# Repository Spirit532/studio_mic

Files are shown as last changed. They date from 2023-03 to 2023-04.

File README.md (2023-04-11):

# Simple, high quality condenser microphone for under $100

I needed a good quality microphone, but all of the options available were either a bit pricy or just not really good in performance, so I decided to build my own.

The microphone build uses a clone RK12/CK12 capsule($40-50 on Aliexpress/Ebay/etc, search for "edge terminated capsule"), a U87 donor body($15-30, also Aliexpress, search term "U87 mic"), and a custom preamp board($20-30, this project).

The board is very simple, yet high performance - it uses a dual FET input opamp in a single package to both convert the capsule's impedance and provide a differential signal, while the bias is provided by a slightly cursed hex schmitt trigger inverter charge pump.

With the setup pictured below, the results are, to the non-audiophool ear, perfect. There is practically no self-noise due to the simplicity of the circuit and performance of the chosen opamp, plenty of dynamic range, and no signal distortion/"coloration". You get exactly what the capsule sees on the XLR connector.

#### Notes about component choice
  1. You can use pretty much any FET input opamp, **however** you must pay close attention to the quiescent current. This circuit uses a fairly high impedance power path, and the phantom power standard can't provide much current in the first place. Total power consumption of the two opamps should be no more than ~7-8mA(3.5-4mA per).

  2. Same goes for the hex inverter in terms of power consumption, but otherwise anything will do. You can substitute the part with any 40106 clone of similar functionality.
  
  3. Take care to purchase high voltage rated capacitors where specified - this is important! Ceramic capacitors lose capacitance at higher voltages, so X7R class caps rated at 100V or more are preferred(this won't explicitly solve derating, but it will help). All values are  readily available in 0805 size, so it's not an issue.

  4. Choose NP0/C0G capacitors for ceramics if your budget allows. They'll improve performance a little bit, but not by a whole lot. (this will solve derating, but at significant cost)
  
The design is licensed under the MIT license. If you want to build it, go ahead. If you want to sell it, also go ahead, but just mention this page or something. Pretty much none of this is really original and has been done dozens of times(i.e. DJJules/Sound Sleuth over at Instructables, whose circuit I took inspiration from), I just put my own twist on it.

#### Important note about cheap donor bodies
Most cheap donor bodies will come pre-anodized or even pre-painted, including contact surfaces at separation points(circuit cover, headbasket, nut, spacers, etc), __make sure to sand them down__ to expose metal, or you'll pick up tons of mains hum and other external electrical noise!

## Get the board
If you can't make or assemble the board yourself, you can order them here(shared PCBWay project, if you order there I get commission at no cost to you)

https://www.pcbway.com/project/shareproject/Simple_ultra_high_performance_condenser_microphone_circuit_495ce39d.html

## Schematic
(also available as pdf or KiCad 7 sources, see files)

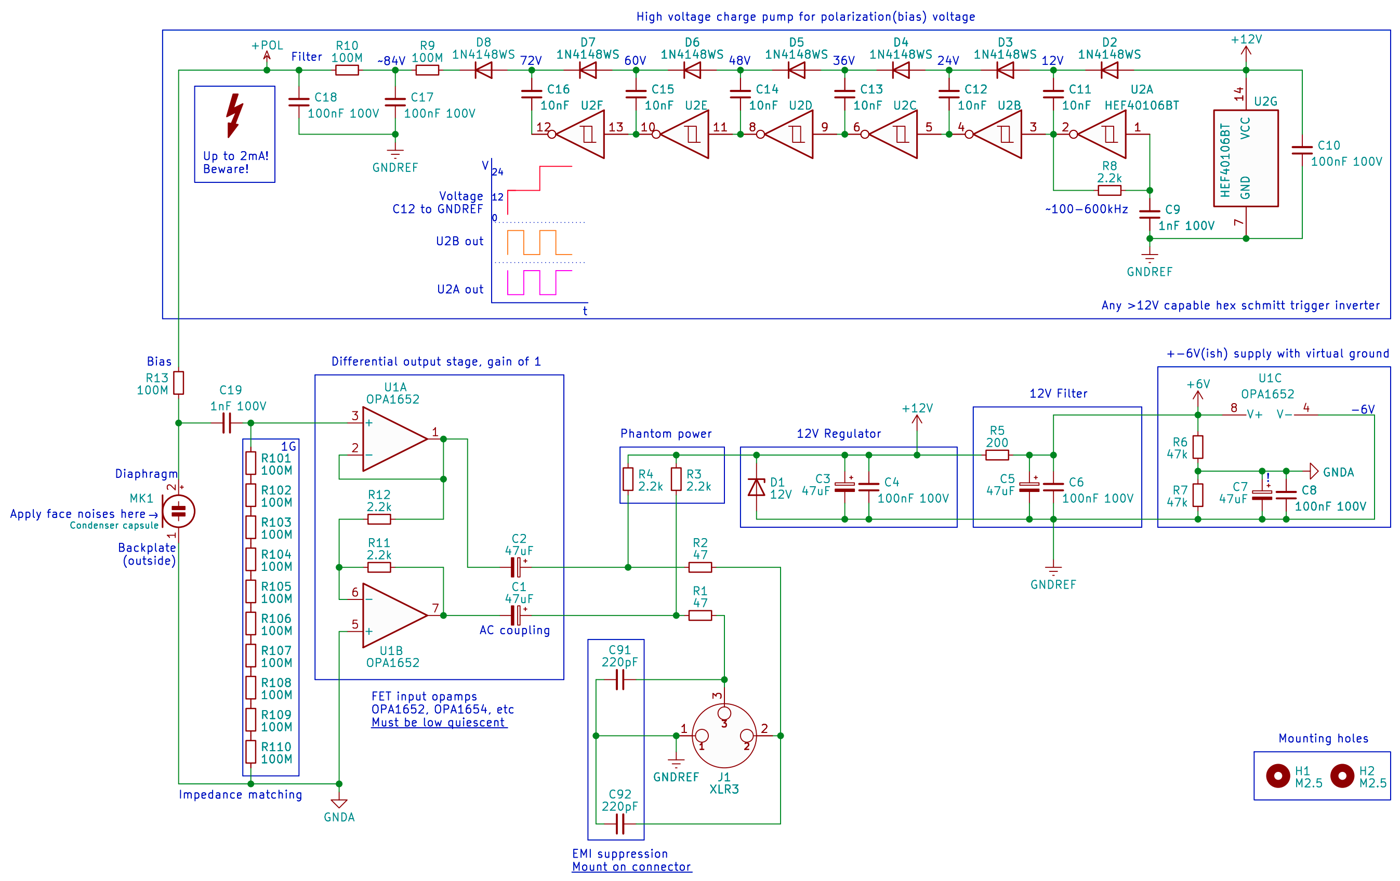
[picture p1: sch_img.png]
Schematic


## PCB render
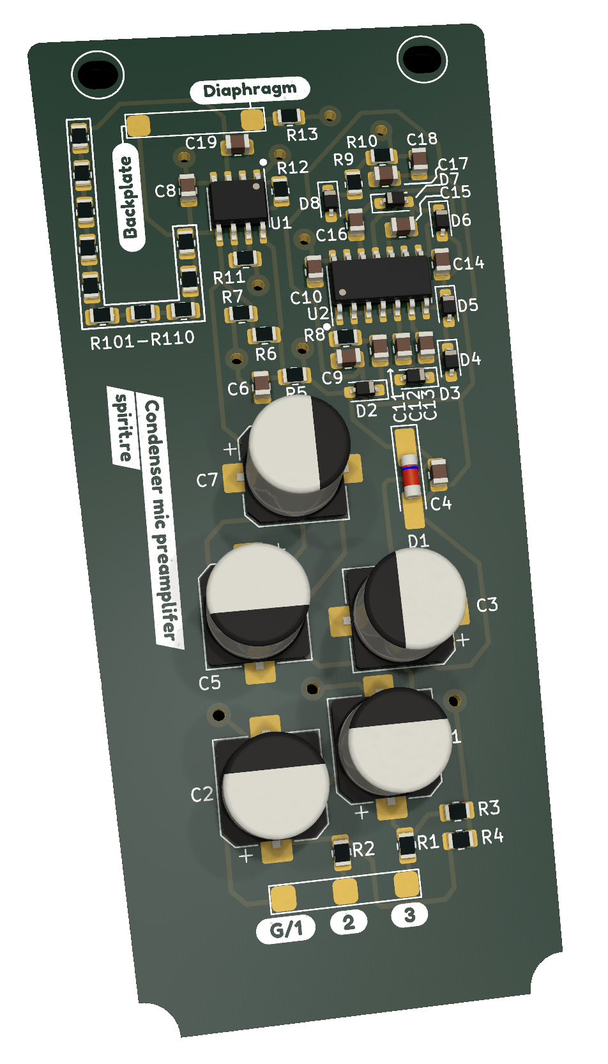
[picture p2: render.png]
Render


## Assembled board, DIY single-layer version(homemade)
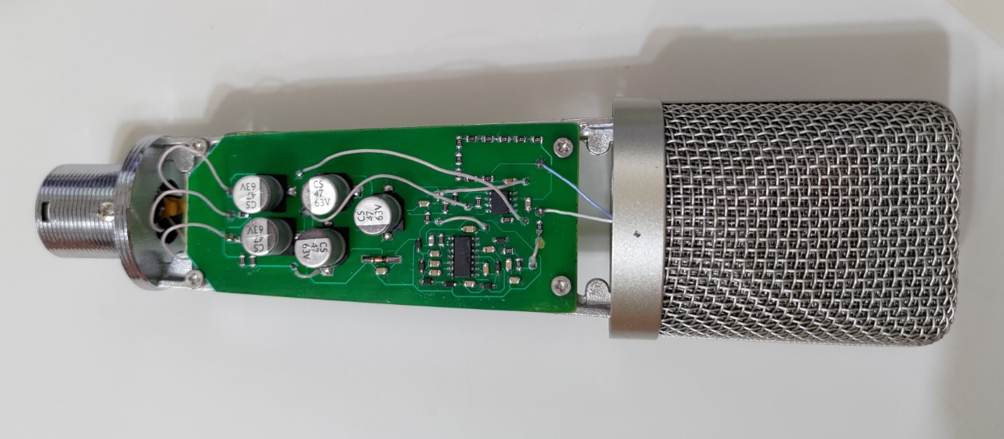
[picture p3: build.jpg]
Build


## Capsule mounted in the donor body
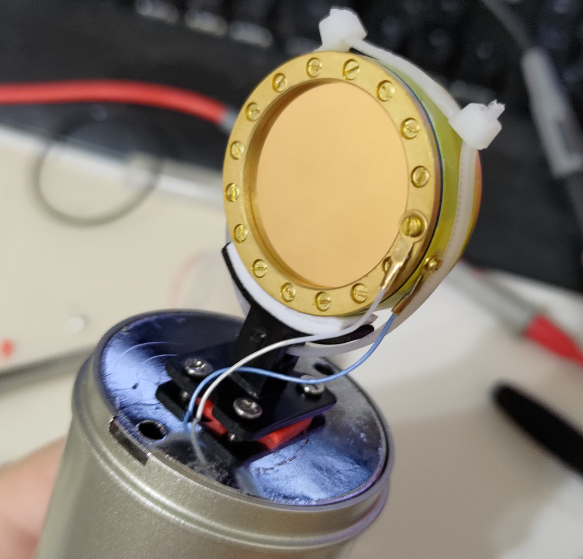
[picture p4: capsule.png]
Capsule


## U87 clone donor body
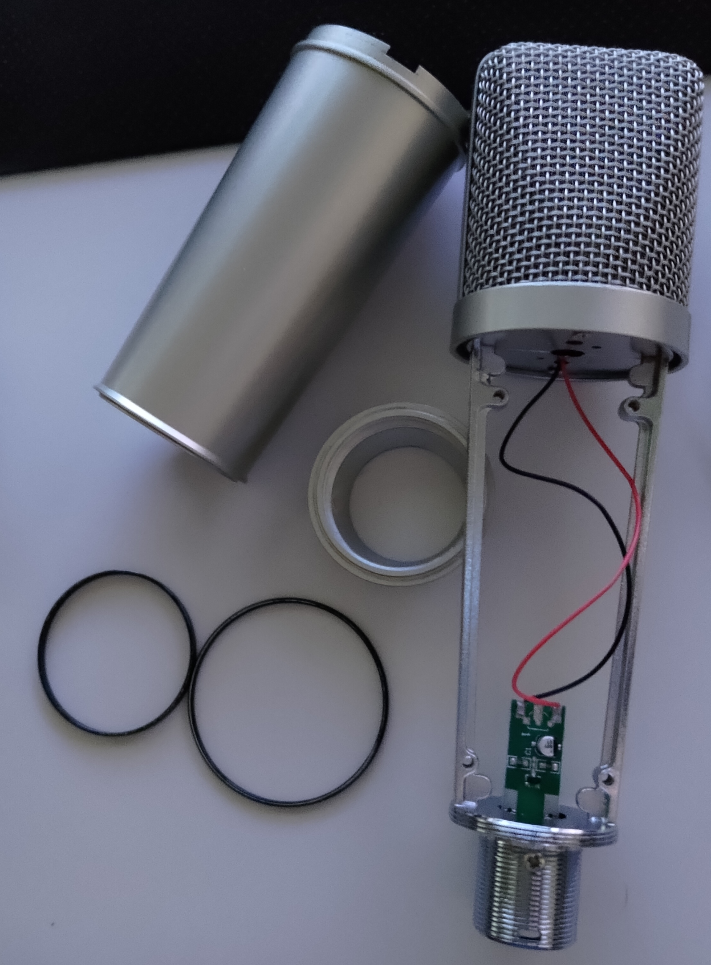
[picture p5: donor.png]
Donor


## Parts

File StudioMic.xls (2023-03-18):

Reference | Value | Footprint | Qty
C1-C3, C5, C7 | 47uF 63V | Capacitor_SMD:CP_Elec_8x10.5 | 5
C4, C6, C8, C10, C17, C18 | 100nF 100V | Capacitor_SMD:C_0805_2012Metric | 6
C9, C19 | 1nF 100V | Capacitor_SMD:C_0805_2012Metric | 2
C11-C16 | 10nF | Capacitor_SMD:C_0805_2012Metric | 6
C91, C92 | 220pF | Mount on connector, not on PCB | 2
D1 | 12V | Diode_SMD:D_MiniMELF_Handsoldering | 1
D2-D8 | 1N4148WS | Diode_SMD:D_SOD-323_HandSoldering | 7
H1, H2 | Screw, M2.5 | PCB mounting | 4
J1 | U87 housing, XLR connector | Comes with the housing | 0
MK1 | Condenser capsule | CK12, K67, K47, M7, pick one | 1
R1, R2 | 47 | Resistor_SMD:R_0805_2012Metric | 2
R3, R4, R8, R11, R12 | 2.2k | Resistor_SMD:R_0805_2012Metric | 5
R5 | 200 | Resistor_SMD:R_0805_2012Metric | 1
R6, R7 | 47k | Resistor_SMD:R_0805_2012Metric | 2
R9, R10, R13, R101-R110 | 100M | Resistor_SMD:R_0805_2012Metric | 13
U1 | OPA1652 | Package_SO:SOIC-8_3.9x4.9mm_P1.27mm | 1
U2 | HEF40106BT | Package_SO:SO-14_3.9x8.65mm_P1.27mm | 1

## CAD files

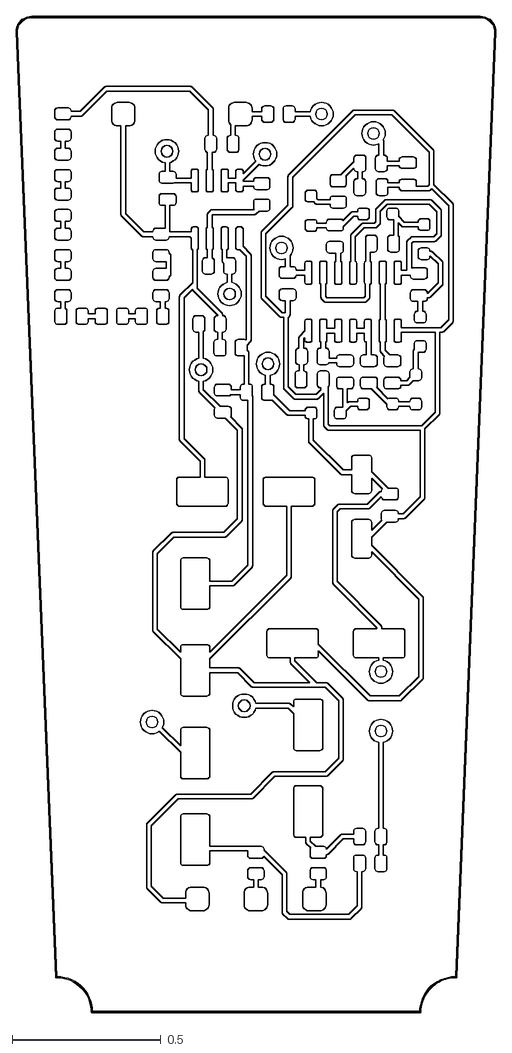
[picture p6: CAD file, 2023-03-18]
DXF/StudioMic-F_Cu.dxf
1.61 x 3.35

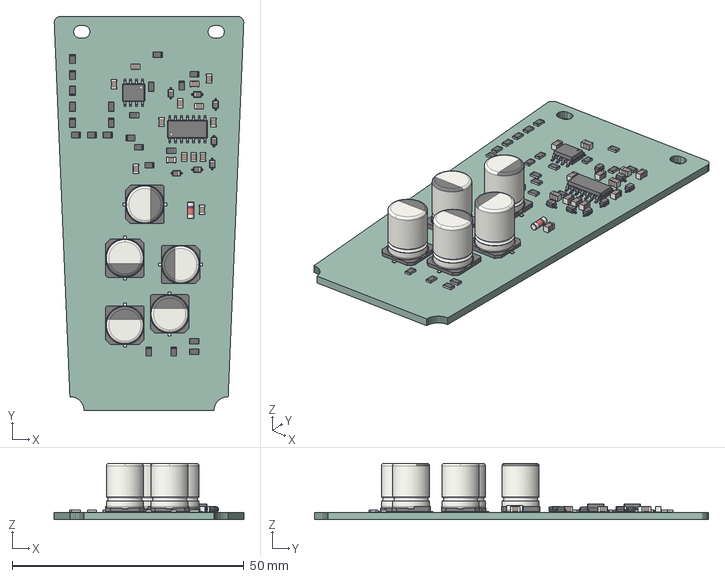
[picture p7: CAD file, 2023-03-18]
StudioMic.step
40.9 x 85.0 x 12.1 mm
PCB

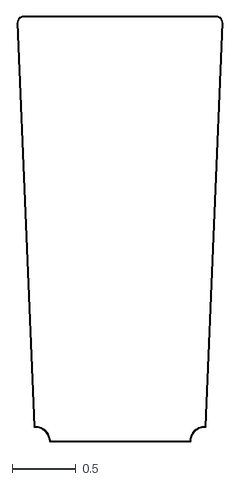
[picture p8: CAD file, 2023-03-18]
DXF/StudioMic-Edge_Cuts.dxf
1.61 x 3.35

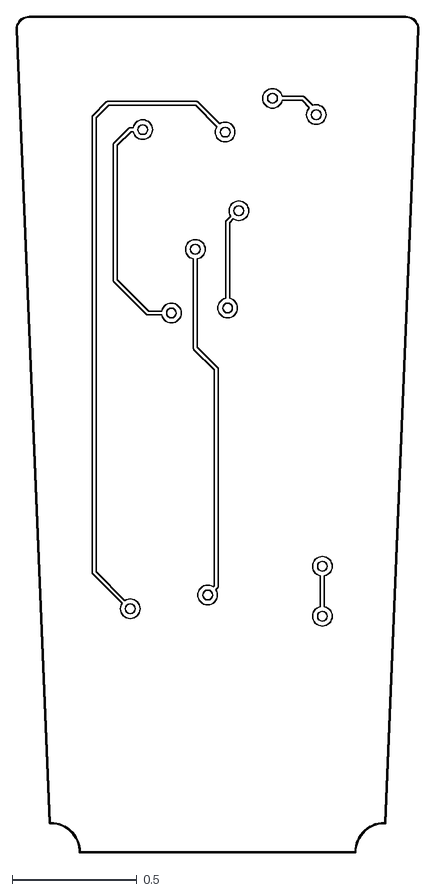
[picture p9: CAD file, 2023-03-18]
DXF/StudioMic-B_Cu.dxf
1.61 x 3.35

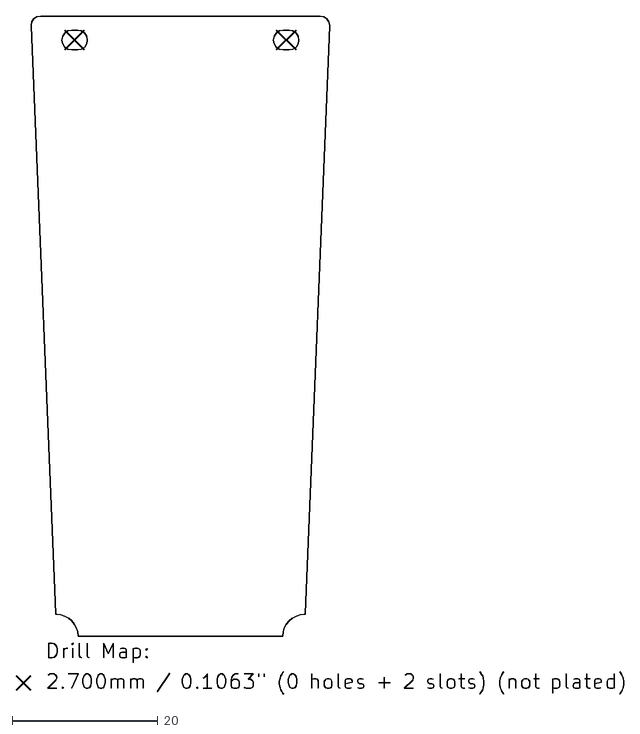
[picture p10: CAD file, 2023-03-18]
DXF/StudioMic-NPTH-drl_map.dxf
83.3 x 92.9

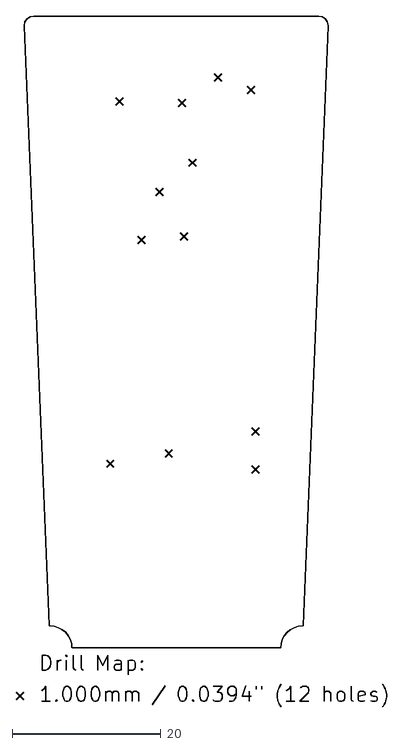
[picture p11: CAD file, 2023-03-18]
DXF/StudioMic-PTH-drl_map.dxf
49.8 x 92.9

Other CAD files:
DXF/StudioMic-B_Mask.dxf
DXF/StudioMic-F_Mask.dxf
DXF/StudioMic-F_Paste.dxf
DXF/StudioMic-F_Silkscreen.dxf

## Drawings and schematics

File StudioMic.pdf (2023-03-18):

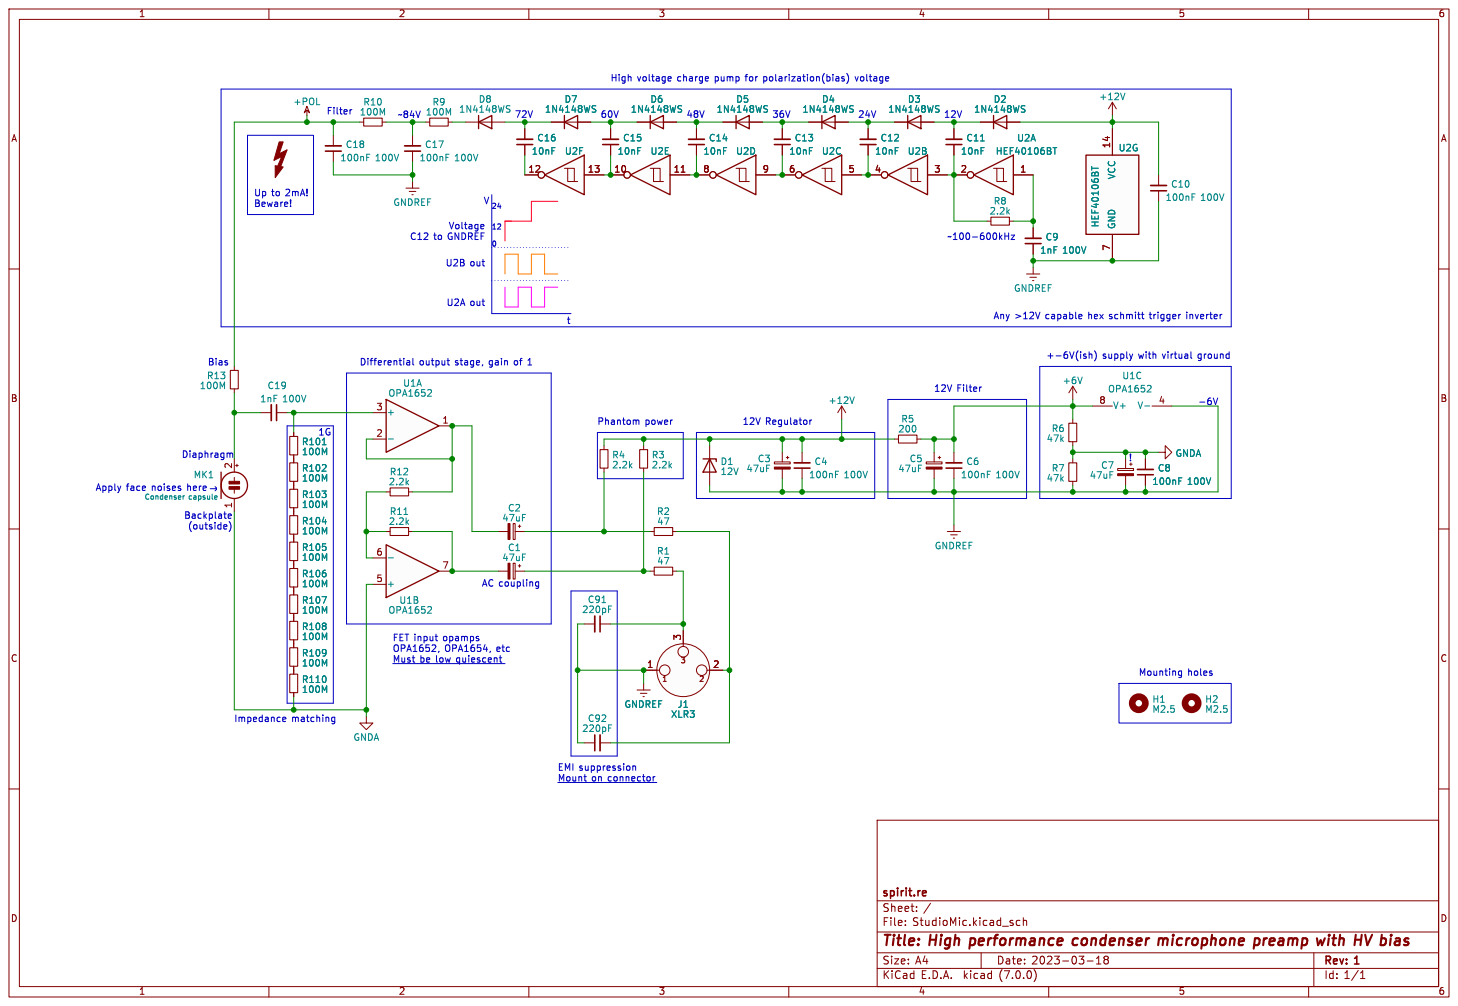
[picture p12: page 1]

~100-600kHz AC coupling FET input opamps OPA1652, OPA1654, etc Must be low quiescent

EMI suppression Mount on connector

File: StudioMic.kicad_sch Sheet: / spirit.re

Id: 1/1 Title: High performance condenser microphone preamp with HV bias

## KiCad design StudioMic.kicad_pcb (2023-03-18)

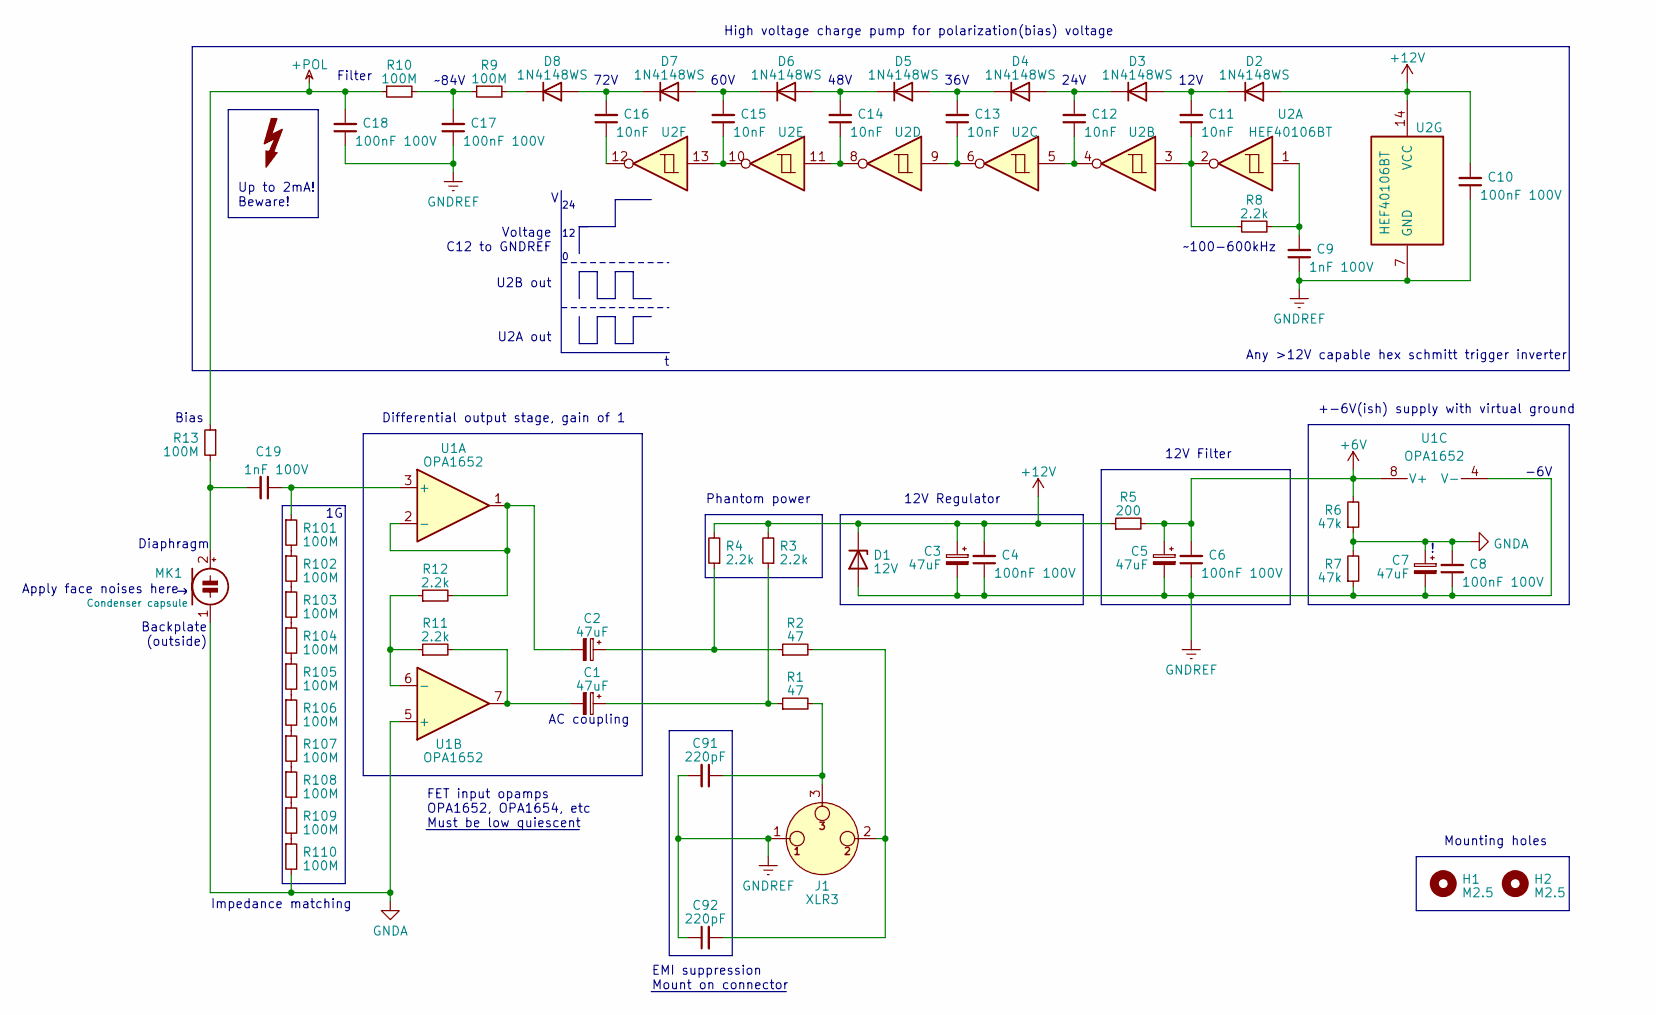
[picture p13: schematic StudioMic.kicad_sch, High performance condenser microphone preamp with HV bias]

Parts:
C1, C2, C3, C5, C7: 47uF; CP_Elec_8x10.5
C4, C6, C8, C10, C17, C18: 100nF 100V; C_0805_2012Metric
C9, C19: 1nF 100V; C_0805_2012Metric
C11, C12, C13, C14, C15, C16: 10nF; C_0805_2012Metric
C91, C92: 220pF
D1: 12V; D_MiniMELF_Handsoldering
D2, D3, D4, D5, D6, D7, D8: 1N4148WS; D_SOD-323_HandSoldering
H1, H2: M2.5; MountingHole_2.7mm_M2.5_ISO14580
J1: XLR3; Pads_3pin_10mm
MK1: Condenser capsule; Pads_2pin_10mm
R1, R2: 47; R_0805_2012Metric
R3, R4, R8, R11, R12: 2.2k; R_0805_2012Metric
R5: 200; R_0805_2012Metric
R6, R7: 47k; R_0805_2012Metric
R9, R10, R13, R101, R102, R103, R104, R105, R106, R107, R108, R109, R110: 100M; R_0805_2012Metric
U1: OPA1652; SOIC-8_3.9x4.9mm_P1.27mm
U2: HEF40106BT; SO-14_3.9x8.65mm_P1.27mm

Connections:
+6V: C5.1, C6.2, R5.2, R6.2, U1.8 (V+)
+12V: C3.1, C4.2, C10.2, D1.1 (K), D2.2 (A), R3.2, R4.2, R5.1, U2.14 (VCC)
GNDA: C7.1, C8.2, MK1.1 (-), R6.1, R7.2, R110.2, U1.5 (+)
GNDREF: C3.2, C4.1, C5.2, C6.1, C7.2, C8.1, C9.1, C10.1, C17.1, C18.1, C91.2, C92.1, D1.2 (A), J1.1, R7.1, U1.4 (V-), U2.7 (GND)
HT: C18.2, R10.1, R13.1
unnamed: C1.1, R1.1, R3.1
unnamed: C1.2, R11.2, U1.7
unnamed: C2.1, R2.1, R4.1
unnamed: C9.2, R8.2, U2.1
unnamed: C11.1, R8.1, U2.2, U2.3
unnamed: C12.1, U2.4, U2.5
unnamed: C13.1, U2.6, U2.9
unnamed: C14.1, U2.8, U2.11
unnamed: C15.1, U2.10, U2.13
unnamed: C16.1, U2.12
unnamed: C17.2, R9.1, R10.2
unnamed: C91.1, J1.3, R1.2
unnamed: C92.2, J1.2, R2.2
unnamed: C11.2, D2.1 (K), D3.2 (A)
unnamed: C12.2, D3.1 (K), D4.2 (A)
unnamed: C13.2, D4.1 (K), D5.2 (A)
unnamed: C14.2, D5.1 (K), D6.2 (A)
unnamed: C15.2, D6.1 (K), D7.2 (A)
unnamed: C16.2, D7.1 (K), D8.2 (A)
unnamed: D8.1 (K), R9.2
unnamed: C19.2, MK1.2 (+), R13.2
unnamed: R101.2, R102.1
unnamed: R102.2, R103.1
unnamed: R103.2, R104.1
unnamed: R104.2, R105.1
unnamed: R105.2, R106.1
unnamed: R106.2, R107.1
unnamed: R107.2, R108.1
unnamed: R108.2, R109.1
unnamed: R109.2, R110.1
unnamed: C19.1, R101.1, U1.3 (+)
unnamed: C2.2, R12.2, U1.1, U1.2 (-)
unnamed: R11.1, R12.1, U1.6 (-)

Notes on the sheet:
12V
Phantom power
Impedance matching
60V
Filter
Bias
Up to 2mA! Beware!
Mounting holes
EMI suppression Mount on connector
FET input opamps OPA1652, OPA1654, etc Must be low quiescent
36V
-6V
24V
Voltage C12 to GNDREF
Differential output stage, gain of 1
12V Regulator
12V Filter
~84V
~100-600kHz
U2A out
U2B out
48V
Any >12V capable hex schmitt trigger inverter
Backplate (outside)
+-6V(ish) supply with virtual ground
AC coupling
Diaphragm
Apply face noises here
High voltage charge pump for polarization(bias) voltage
72V

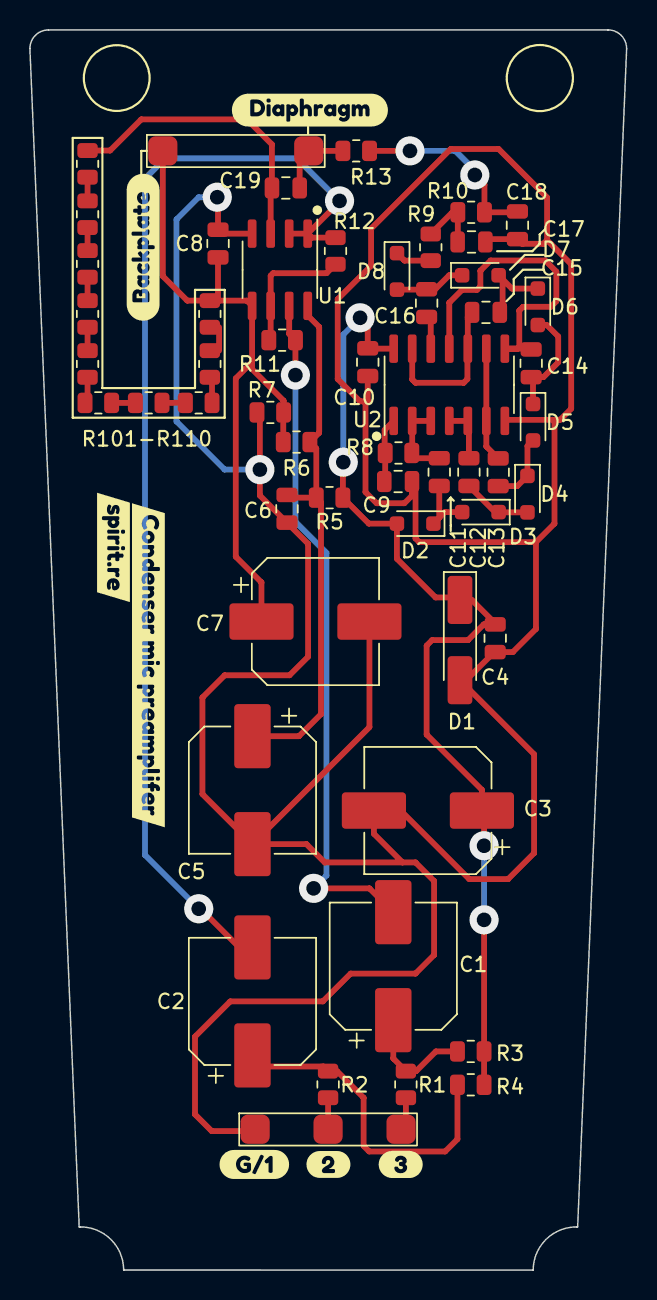
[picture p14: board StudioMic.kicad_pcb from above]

Board: 2 copper layers, 40.9 x 85.0 mm, 63 parts (0 on the bottom side), 38 nets.

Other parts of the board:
kibuzzard-64153C1C: G***; kibuzzard-64153C1C
kibuzzard-64153C31: G***; kibuzzard-64153C31
kibuzzard-640955D5: G***; kibuzzard-640955D5
kibuzzard-640955DC: G***; kibuzzard-640955DC
kibuzzard-640955F0: G***; kibuzzard-640955F0
kibuzzard-6409565D: G***; kibuzzard-6409565D
kibuzzard-64095693: G***; kibuzzard-64095693

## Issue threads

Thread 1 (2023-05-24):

Ground connected to body?

KoviRobi, 2023-05-24:
Hi,

Thanks for the schematics and instructions, I've managed to build my own :) I wouldn't be able to come up with the design/know how to tune it but I did manage to understand how it works, with the help of the internet. I was just wondering, is it intentional that the PCB ground traces are not connected to the body? I did do the sanding of the body, it was all electrically connected from one end to the other, but I had huge amounts of hum (about twice the signal strength) until I connected the ground of the XLR to the body. Maybe the mounting holes could be plated and connected to the ground if this is necessary, or should this not have been necessary and maybe I did something wrong?

Thanks,
Rob

Spirit532, 2023-05-24:
Note the GNDREF near the XLR connector, J1, and capacitors C91 and C92. GNDREF is already connected through the XLR wiring(on pin 1), which should ground the body _at the connector_, mechenically. C91 and C92 must also be mounted on the connector pins directly.

KoviRobi, 2023-05-25:
Yeah I think it's that the body isn't connected to the XLR connector -- there is actually a separate tab on the XLR connector that connects to the screw/body (and this isn't pin 1, nor is it connected to it) so that would be it, thanks!

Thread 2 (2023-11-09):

Diagnosing a dull pop, followed by dull/dark and quiet output

CarlosSpicyWiener, 2023-11-09:
Thank you for the fantastic design and instructions. I'm hoping your experience might help diagnose a problem I'm having.

**Issue:**
After a few minutes of use (varies, anywhere from 1 to 10 minutes), my microphone outputs a dull pop(s), after which the output goes very dull/dark and quiet.

I have attached:
- audio and an image illustrating the pop and change in output.
- an image of my board (in case there is an obvious error in the assembly?).

[Audio.zip](https://github.com/Spirit532/studio_mic/files/13303083/Audio.zip)
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

**Things I have tried so far (in case it help troubleshoot):**
- Unplugging and leaving overnight resolves the issue temporarily. The output is back to normal, until a few minutes of use reproduces the same issue.
- The issue is occurs even if I don't interact with the mic (i.e. it's not triggered by input or humidity from my breath, it happens even if recording silence from a distance).
- I don't think it is a faulty capsule, board, connector or cable. I have tried multiple of each (I was building two mics so had spares).
- It don't think the issue is my audio interface. Mine has two inputs/preamps (Arturia Minifuse 2), and the issue happens with both. Switching between inputs doesn't resolve the issue once it starts. The issue doesn't persist if you switch to a second identical mic (again, I was building two mics so was able to test this).

**Do you have any ideas what the issue could be? Is it possibly a phantom power issue? Thanks in advance.**

Spirit532, 2023-11-09:
Thanks for building the design!

I encountered this exact issue in a previous design revision, where I didn't have the R101-R110 chain discharging the diaphragm, which was simply slamming the input of the opamp(U1A pin 3) beyond its rail, causing it to go silent.
The reason it's detected as a pop is because mics are AC coupled(C2/C1).
You can verify that this is the case by measuring the output of U1A(pin 1). When it goes quiet, you should see the chip saturate and sit high. If it doesn't sit high, then it's either your capsules or potentially 1/5(see below).

There may be multiple causes, any one of which would lead to this, in the order of easiest to test(but not necessarily the most likely):
1 - Your capsules are just built differently to mine and can't handle the high of a bias. You may attempt to lower the bias voltage by sequentially removing C16&D7 and shorting the nodes labelled 72V and 60V, then doing the same for C15&D6, 72 -> 48V if it's not enough.

2 - The 1G bleeder at the input needs to be smaller. You may short up to... I don't know, let's say 5 resistors in the R101-R110 chain, halving the total resistance.

3 - The board isn't clean enough(and it won't be if you do №4). It must be perfectly clean. Spotless. No finger grease or dust. I use brake cleaner(the non-chlorinated kind), followed by a distilled water wash, followed by drying with isopropyl alcohol.

4 - Your board's solder mask is black, which may be slightly conductive(even though it's not carbon, obviously). At these currents, dealing essentially entirely with electrostatics, that may be enough to cause problems. Not much you can do, but maybe scraping it away around the different areas highlighted in blue, all the way to the substrate.

5 - Your capsules are already wet, not from your breath but improper storage(including at the factory or in the mail). Unfortunately it's really hard to say how to dry a capsule correctly, but what seems to work for others is either placing it in a sealed container with a pile of fresh desiccant next to it for a few days, or by baking it in a (clean!) oven at no more than 40C for 5-10 hours. The latter may cause permanent damage to the capsule, especially if the oven overshoots to 50-60C.

andicniko, 2023-11-10:
Great answer thank you! Problem solved.

Yes it was the chip saturating and sitting high. I can also confirm it was because my capsules seem to be built differently.

Solution: I ordered new capsules that matched your pictures in appearance (yellow tape, blue and white lead wires) and can't reproduce the issue anymore. It was cheap enough to try before doing any surgery on the PCB, and luckily worked :).

I guess my problematic capsules (green tape, yellow lead wires) came from a different factory and some unwritten specification was different.

It is a fantastic mic by the way. Thanks again.

Spirit532, 2023-11-10:
You're welcome :)

The other capsules probably had too high of a leakage current. Probably solvable by reducing the 1G chain's resistance.
